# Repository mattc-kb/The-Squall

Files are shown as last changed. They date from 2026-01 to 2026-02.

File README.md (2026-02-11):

# The Squall v1.0
Wireless split keyboard build based off of the Tempest which in turn is based on the Temper and Chocofi.

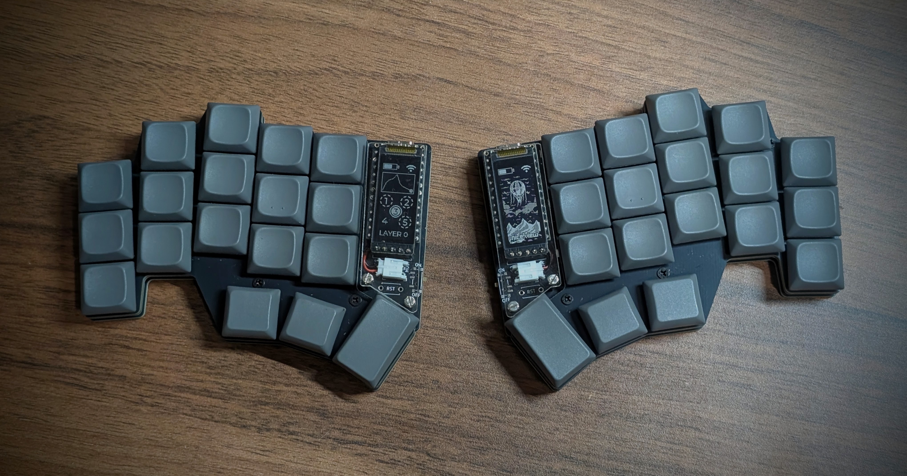
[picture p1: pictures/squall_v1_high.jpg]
Squall v1.0


I wanted a splay for the outer columns, but a slightly more agressive stagger than the Tempestv2 while retaining the thumb cluster placement of the Temper and Chocofi.

Included in the repo are the ergogen config and footprint files as well as the Kicad output and gerbers for both the PCB and the plates.

### Bill of materials:
36 smd diodes
36 Choc hotswap sockets
2 NiceNano / nRF52840 BLE controllers
2 JST sockets
2 smd power switches
2 reset switches

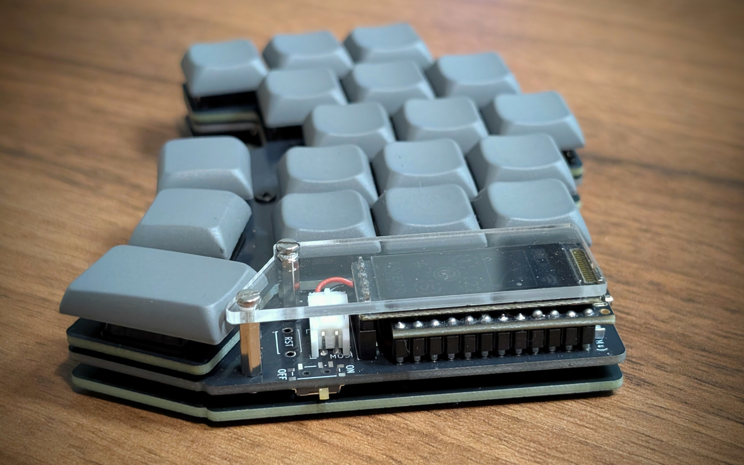
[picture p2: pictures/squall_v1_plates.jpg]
Squall v1.0 plates


## Assembly:
Soldering of the jumpers for the controller, NiceView and the power connector is done on the back of the board. The same side as the sockets and diodes.
The power switch is also intended to be mounted on the underside of board.

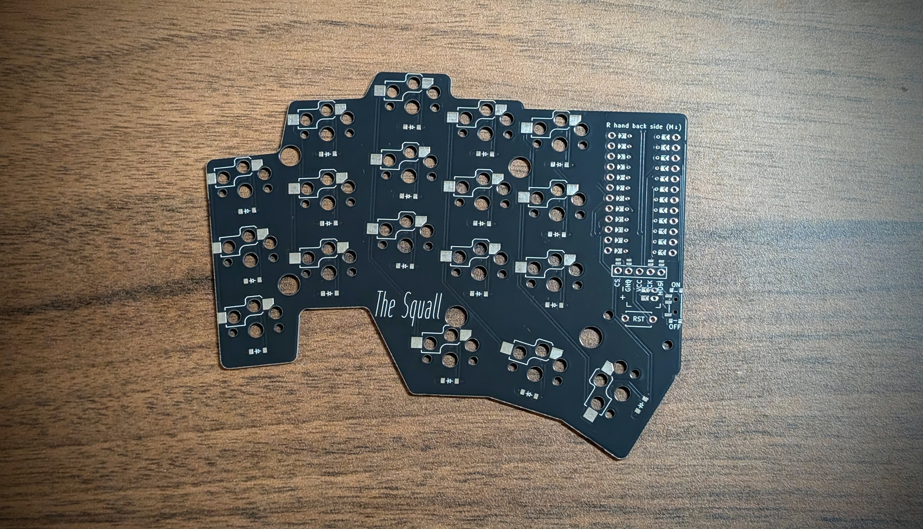
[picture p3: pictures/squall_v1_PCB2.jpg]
Squall v1.0 pcb


## Firmware:
I have loaded and I am currently using Corne firmware successfully on this board.

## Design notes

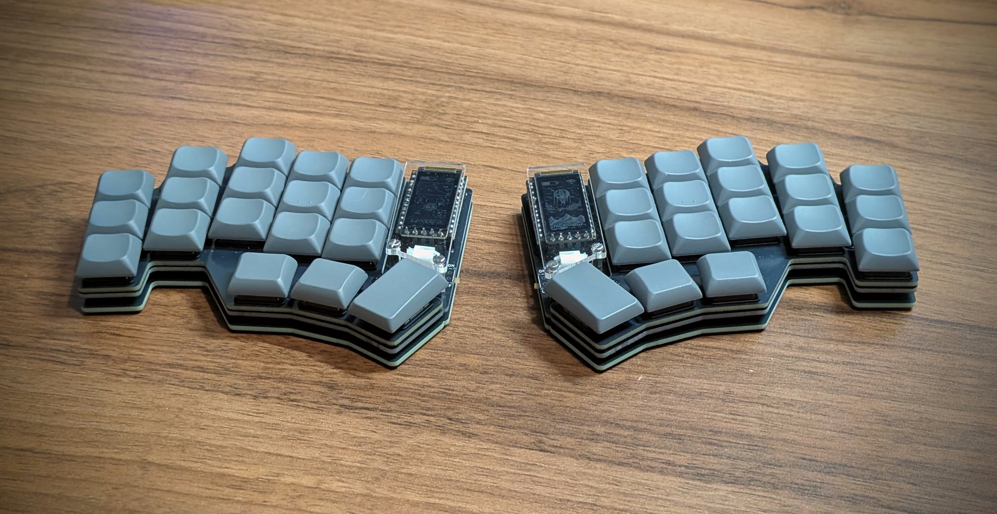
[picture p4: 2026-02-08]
pictures/squall_v1_low.jpg

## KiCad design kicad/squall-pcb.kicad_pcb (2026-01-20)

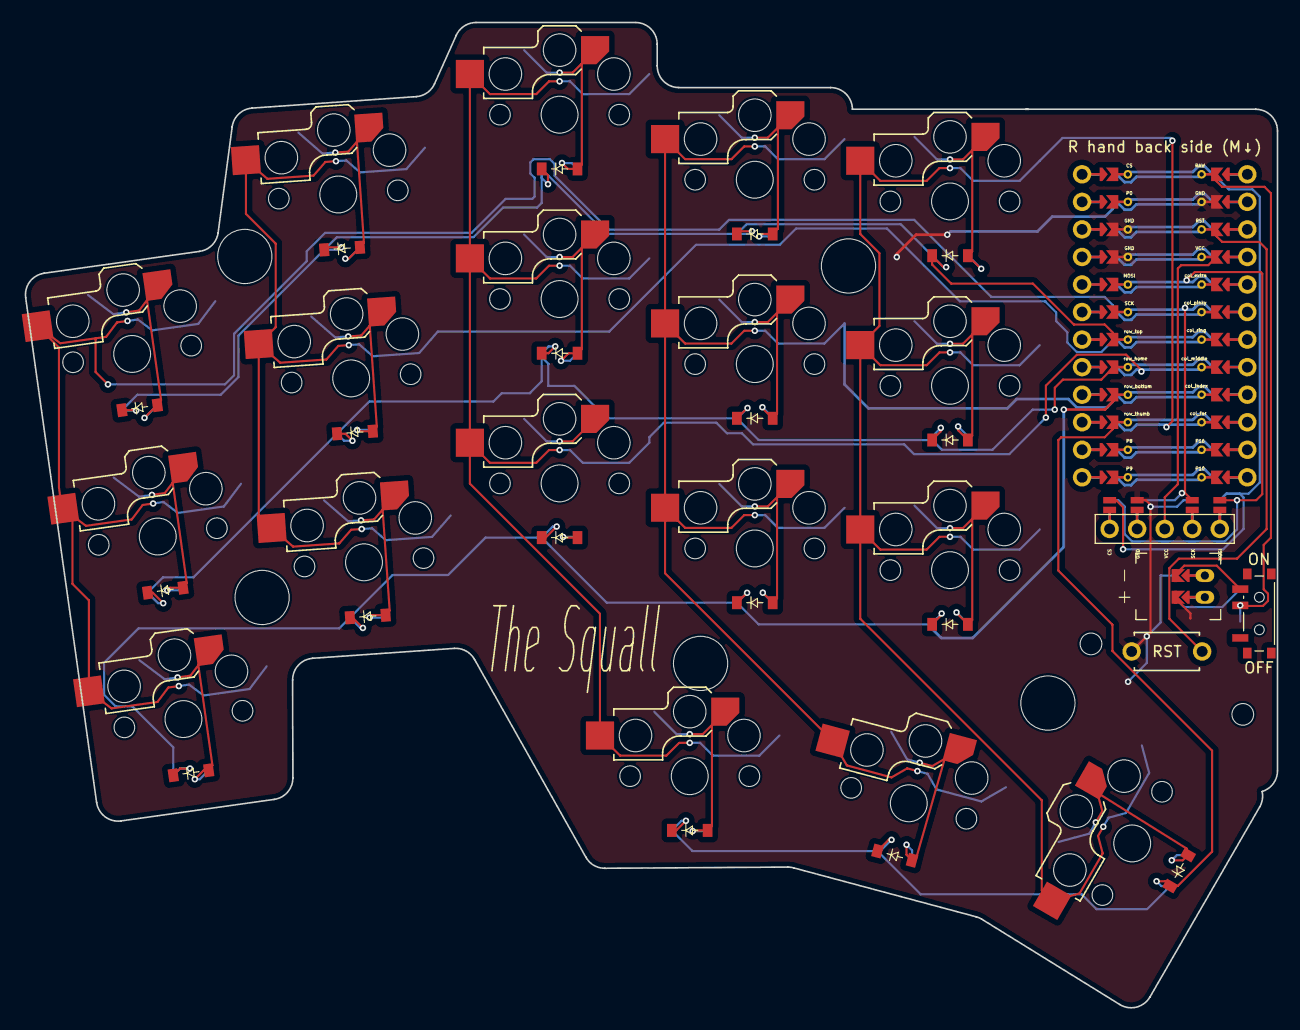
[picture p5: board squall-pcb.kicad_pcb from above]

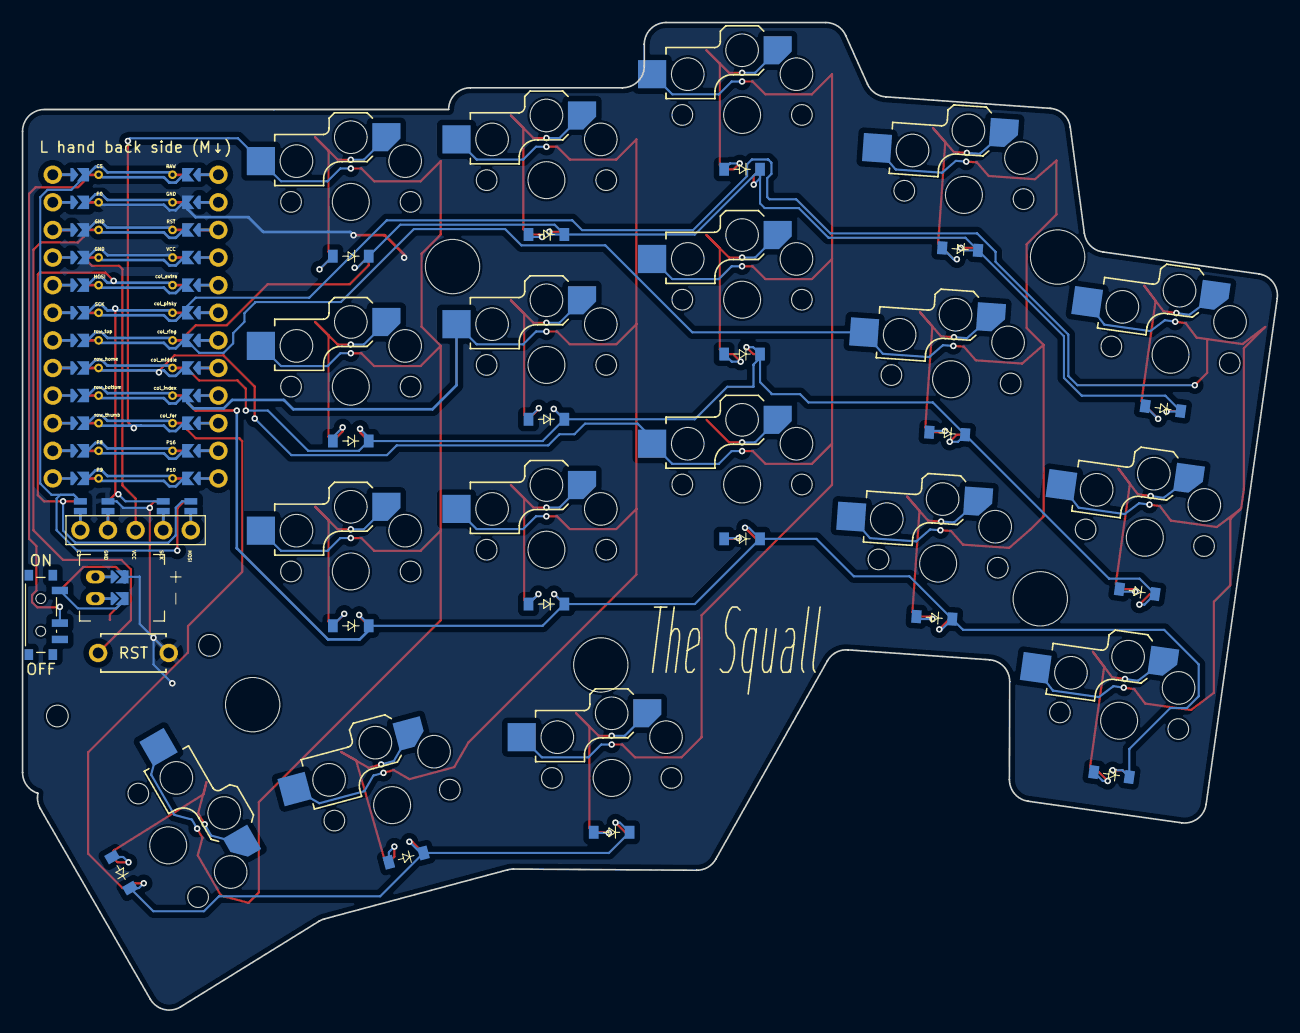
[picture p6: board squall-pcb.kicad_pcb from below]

Board: 2 copper layers, 115.5 x 90.9 mm, 48 parts (18 on the bottom side), 41 nets.

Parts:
D1, D2, D3, D4, D5, D6, D7, D8, D9, D10, D11, D12, D13, D14, D15, D16, D17, D18: diode_tht_sod123
DISP1: display_nice_view
JST1: battery_connector_jst_ph_2
MCU1: mcu_nice_nano
MH1, MH2, MH3, MH4, MH5, MH6, MH7: mounting_hole_npth
PWR1: power_switch_smd_side
RST1: reset_switch_tht_top
S1, S2, S3, S4, S5, S6, S7, S8, S9, S10, S11, S12, S13, S14, S15, S16, S17, S18: switch_choc_v1_v2

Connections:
BAT_P: JST1.1, PWR1.1, PWR1.3
CS: DISP1.14, DISP1.24, MCU1.124
DISP1_1: DISP1.1, DISP1.10, DISP1.23
DISP1_2: DISP1.2, DISP1.11, DISP1.22
DISP1_4: DISP1.4, DISP1.12, DISP1.21
DISP1_5: DISP1.5, DISP1.13, DISP1.20
GND: DISP1.15, DISP1.25, JST1.2, MCU1.102, MCU1.121, MCU1.122, RST1.2
JST1_1: JST1.11, JST1.21, JST1.31
JST1_2: JST1.12, JST1.22, JST1.32
MOSI: DISP1.17, DISP1.27, MCU1.120
RAW: MCU1.101, PWR1.2
RST: MCU1.103, RST1.1
SCK: DISP1.16, DISP1.26, MCU1.119
VCC: DISP1.3, MCU1.104
col_far: MCU1.110, S13.2, S14.2, S15.2, S18.2
col_index: MCU1.109, S10.2, S11.2, S12.2, S17.2
col_middle: MCU1.108, S7.2, S8.2, S9.2, S16.2
col_pinky: MCU1.106, S1.2, S2.2, S3.2
col_ring: MCU1.107, S4.2, S5.2, S6.2
far_bottom: D13.2, S13.1
far_home: D14.2, S14.1
far_top: D15.2, S15.1
index_bottom: D10.2, S10.1
index_home: D11.2, S11.1
index_top: D12.2, S12.1
inner_cluster: D16.2, S16.1
middle_bottom: D7.2, S7.1
middle_cluster: D17.2, S17.1
middle_home: D8.2, S8.1
middle_top: D9.2, S9.1
outer_cluster: D18.2, S18.1
pinky_bottom: D1.2, S1.1
pinky_home: D2.2, S2.1
pinky_top: D3.2, S3.1
ring_bottom: D4.2, S4.1
ring_home: D5.2, S5.1
ring_top: D6.2, S6.1
row_bottom: D1.1, D4.1, D7.1, D10.1, D13.1, MCU1.116
row_home: D2.1, D5.1, D8.1, D11.1, D14.1, MCU1.117
row_thumb: D16.1, D17.1, D18.1, MCU1.115
row_top: D3.1, D6.1, D9.1, D12.1, D15.1, MCU1.118

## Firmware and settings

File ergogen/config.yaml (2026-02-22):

meta:
  engine: 4.1.0
  name: Temper Squall

units:
  # Spacing Variables
  kx: cx # standard choc width of 18mm
  ky: cy # standard choc hight of 17mm
  # Padding Variables
  px: kx + 4
  py: ky + 4
  # change web view to choc sizes
  $default_width: 18 
  $default_height: 17
  
  standoff_size: 5 #size for standoff holes on pcb
  screen_standoff_size: 2

  hole1_x: -0.5 kx - 0
  hole1_y: -0.3 ky - 0

  hole2_x: -0.52 kx
  hole2_y: -0.35 ky

  hole3_x: 0.5 kx + 1
  hole3_y: 0.75 ky - 0.5

  hole4_x: 0.5 kx - 14
  hole4_y: -0.5 ky - 2.1

  hole5_x: -0.5 kx - 0.6
  hole5_y: -1.24 ky + 1.5

  voff: 4

points:
  zones:
    matrix:
      anchor: # Fix placement on KICAD sheet
        shift: [100, -100]
      key:
        padding: 1ky
        spread: 1kx
      rows:
        bottom:
          row_net: row_bottom         
        home:
          row_net: row_home
        top:
          row_net: row_top
      columns:
        pinky:
          key.column_net: col_pinky          
        ring:
          # note the dot notation compared to thumb notation
          key.stagger: 12
          key.splay: -4
          key.spread: 1kx + 0.5 # Avoids clashing of keys when splayed
          key.column_net: col_ring
        middle:
          key.stagger: 6
          key.splay: -4
          key.spread: 1kx + 0.5 # Avoids clashing of keys when splayed
          key.column_net: col_middle
        index:
          key.stagger: -6
          key.column_net: col_index
        far:
          key.stagger: -2
          key.column_net: col_far   
    thumb:
      key:
        padding: 1ky
        spread: 1kx
      anchor:
        ref: matrix_far_bottom
        shift: [-24,-19]
      rows:
        cluster:
          row_net: row_thumb
      columns:
        inner:
          key.column_net: col_middle          
        middle:
          key:
            rotate: -15
            stagger: -2
            shift: [2.2,-0.5]
          key.column_net: col_index
        outer:
          key:
            rotate: -30
            stagger: -4
            shift: [-0.2,-4.8]
            width: 1.5ky
            splay: 90
          key.column_net: col_far

outlines:
  raw:
    - what: rectangle
      where: true
      size: [kx, ky]
  keys:
    - what: rectangle
      where: true
      bound: false
      size: [kx-0.5,ky-0.5]

  # keys without padding
  key-plug:
    - what: rectangle
      where: true
      size: [13.8, 13.8]

  mcu:
    - what: rectangle
      where:
      - ref: matrix_far_top
        shift: [17.7, -20.5 - 2.5]
      size: [25, 63]
      fillet: 2

  board:
    - what: polygon
      operation: stack
      points:
        - ref: matrix_pinky_top
          shift: [-0.5kx,0.5ky]
        - ref: matrix_pinky_top
          shift: [0.5kx,0.5ky]
        - ref: matrix_ring_top
          shift: [-0.5kx,0.5ky]
        - ref: matrix_ring_top
          shift: [0.5kx,0.5ky]
        - ref: matrix_middle_top
          shift: [-0.5kx,0.5ky]
        - ref: matrix_middle_top
          shift: [0.5kx,0.5ky]
        - ref: matrix_index_top
          shift: [-0.5kx,0.5ky]
        - ref: matrix_index_top
          shift: [0.5kx,0.5ky]
        - ref: matrix_far_top
          shift: [-0.5kx,0.5ky]
        - ref: matrix_far_top
          shift: [0.5kx,0.5ky]
        - ref: matrix_far_bottom
          shift: [0.5kx,-0.5ky]  
        - ref: thumb_outer_cluster
          shift: [0.6kx,0.5ky]   
        - ref: thumb_outer_cluster
          shift: [0.6kx,-0.5ky]   
        - ref: thumb_outer_cluster
          shift: [-0.75kx,-0.5ky]  
        - ref: thumb_middle_cluster
          shift: [0.5kx,-0.5ky]   
        - ref: thumb_middle_cluster
          shift: [-0.5kx,-0.5ky]  
        - ref: thumb_inner_cluster
          shift: [-0.5kx,-0.5ky]  
        - ref: matrix_ring_bottom
          shift: [0.5kx,-0.5ky]  
        - ref: matrix_ring_bottom
          shift: [-0.4kx,-0.5ky]  
        - ref: matrix_pinky_bottom
          shift: [0.5kx,-0.5ky]  
        - ref: matrix_pinky_bottom
          shift: [-0.5kx,-0.5ky]   
      fillet: 2

  pcb-board:
    - name: board
    - operation: add
      name: mcu
  combo:
    - name: pcb-board
    - operation: subtract
      name: keys
  top-plate:
    - name: board
    - operation: subtract
      name: key-plug
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
